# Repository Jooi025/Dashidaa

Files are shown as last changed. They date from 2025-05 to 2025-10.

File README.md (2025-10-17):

# Dashidaa
Meet Dashidaa, the robot car companion with a face and a personality! It smiles, blinks, and reacts as you drive. With a rechargeable battery and a smart power system, Dashidaa keeps itself charged and ready for your adventure.
## PCB
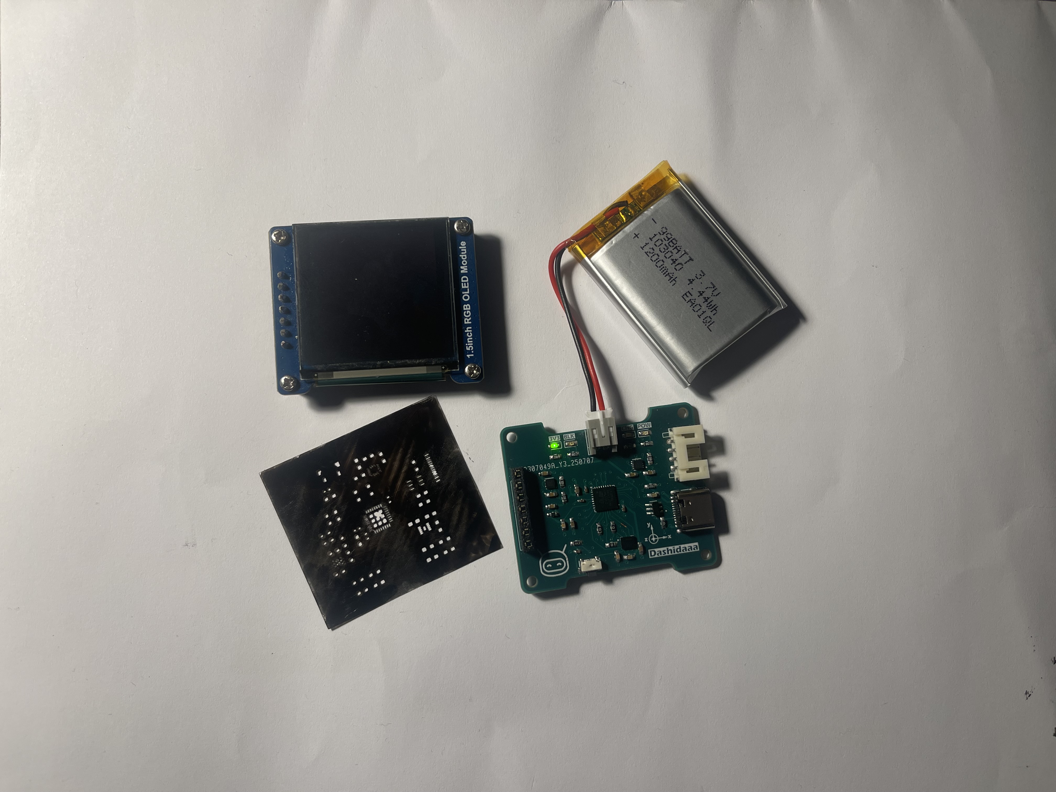
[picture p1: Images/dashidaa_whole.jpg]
PCB whole

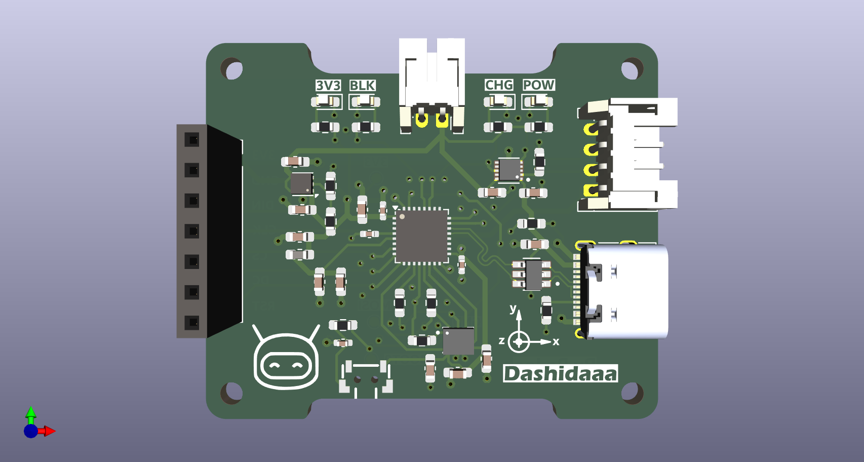
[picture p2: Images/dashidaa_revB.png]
PCB back

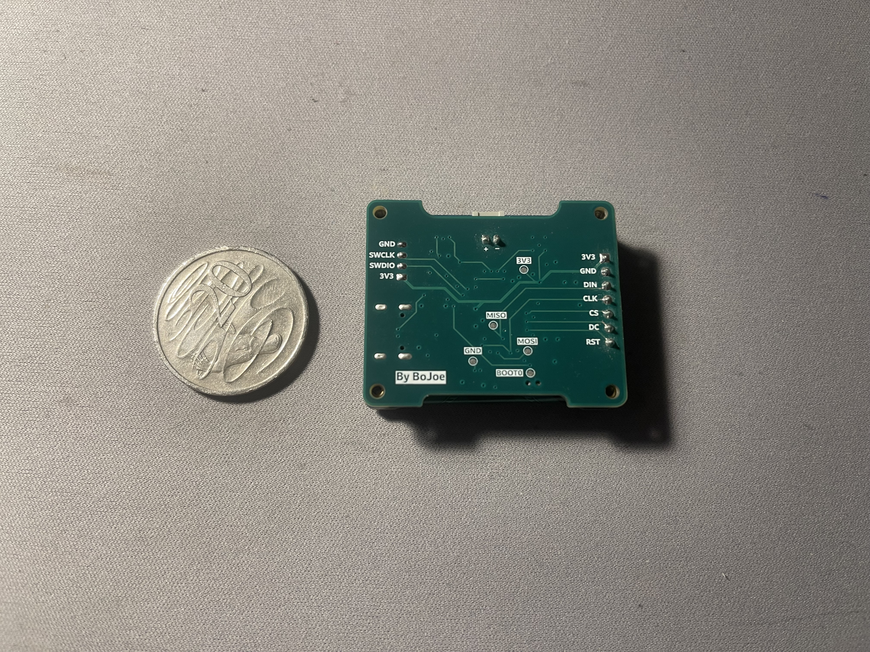
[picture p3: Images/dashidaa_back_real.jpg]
Actual PCB back

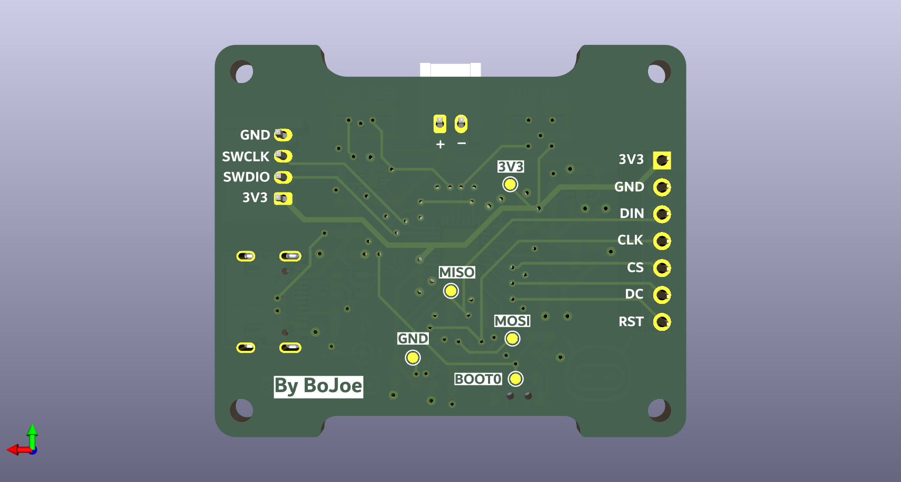
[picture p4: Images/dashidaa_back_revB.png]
PCB front


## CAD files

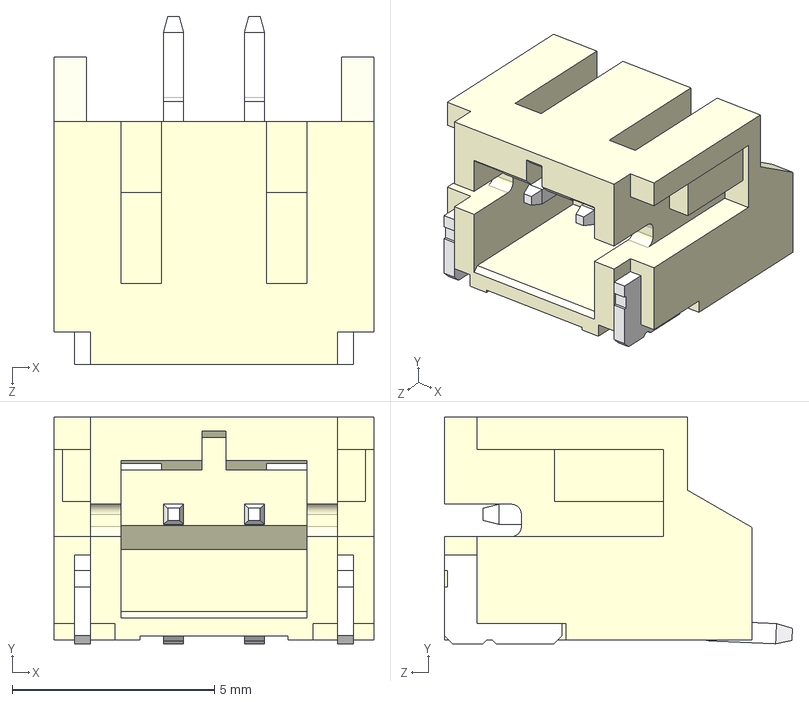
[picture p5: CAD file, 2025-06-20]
Hardware/cad_models/S2B-PH-SM4-TB.STEP
7.90 x 5.60 x 8.60 mm

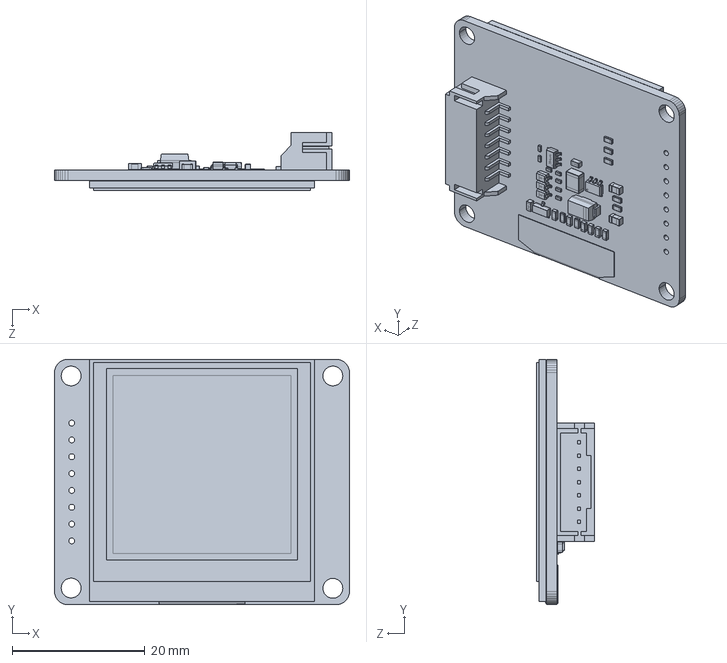
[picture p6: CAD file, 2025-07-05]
Hardware/cad_models/solidworks/1_5inch_oled_module.SLDPRT
44.5 x 37.0 x 8.70 mm

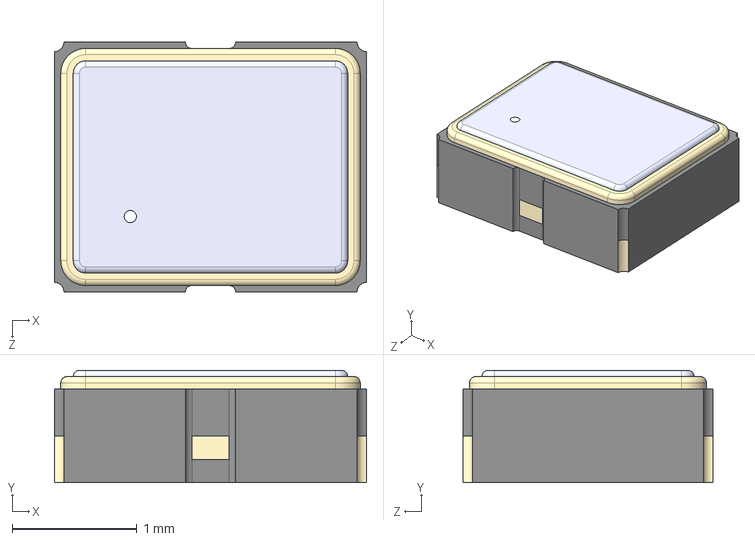
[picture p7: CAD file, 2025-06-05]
Hardware/external_components/ECS_2520MVQ_480_CN_TR/ECS-2520MVQ-480-CN-TR.step
2.50 x 0.9 x 2.00 mm

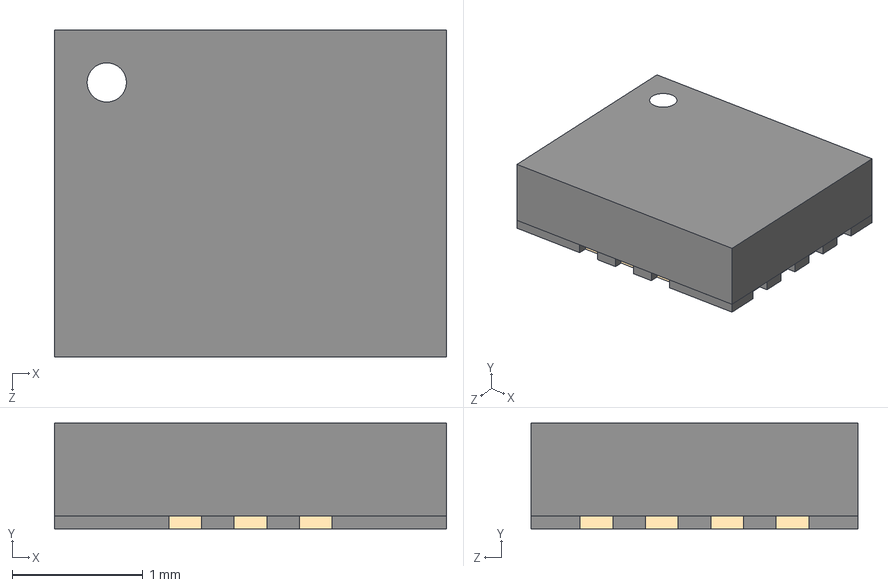
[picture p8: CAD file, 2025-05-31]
Hardware/external_components/ICM42670/ICM-42670-P.step
3.00 x 0.81 x 2.50 mm

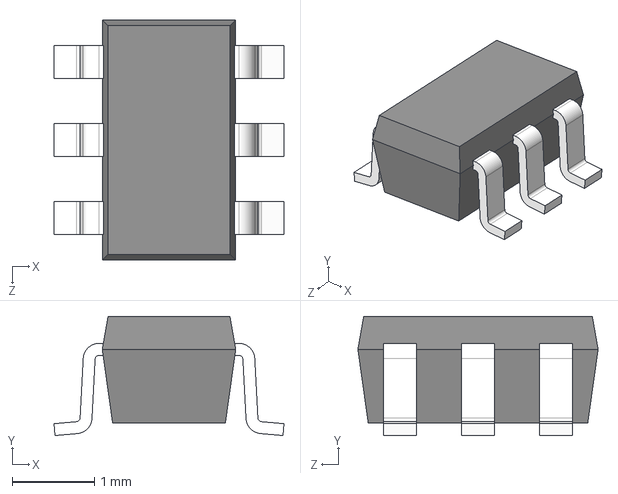
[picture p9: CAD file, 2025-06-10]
Hardware/external_components/USBLC6_2SC6/USBLC6-2SC6.step
2.80 x 1.45 x 2.92 mm

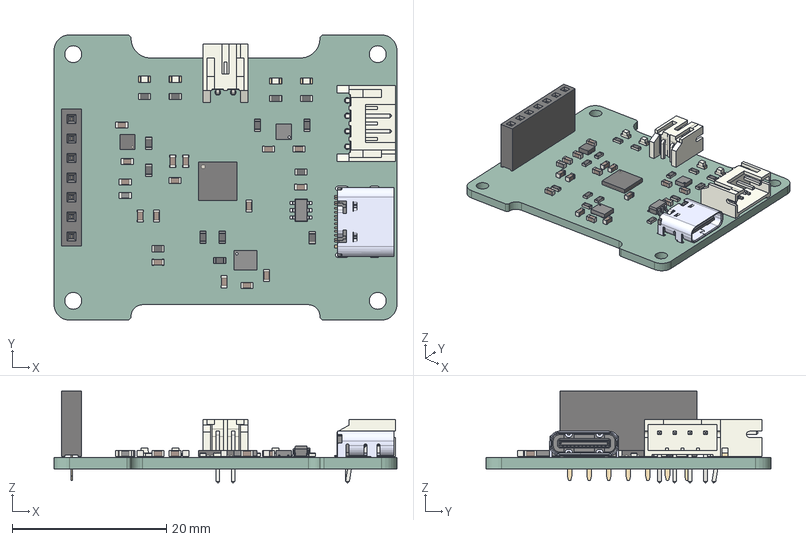
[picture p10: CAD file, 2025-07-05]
Hardware/RCC.step
44.5 x 37.0 x 11.9 mm
C_0603_1608Metric x 16
L_0603_1608Metric
WSON-6-1EP_2x2mm_P0.65mm_EP1x1.6mm
R_0603_1608Metric x 14
JST_PH_S4B-PH-K_1x04_P2.00mm_Horizontal
ICM-42670-P
LED_0603_1608Metric x 4
USB4105GFA_USB4105GFA
JST_PH_S2B-PH-K_1x02_P2.00mm_Horizontal
BQ24040DSQR
PinSocket_1x07_P2.54mm_Vertical
USBLC6-2SC6
QFN-32-1EP_5x5mm_P0.5mm_EP3.45x3.45mm
RCC_PCB

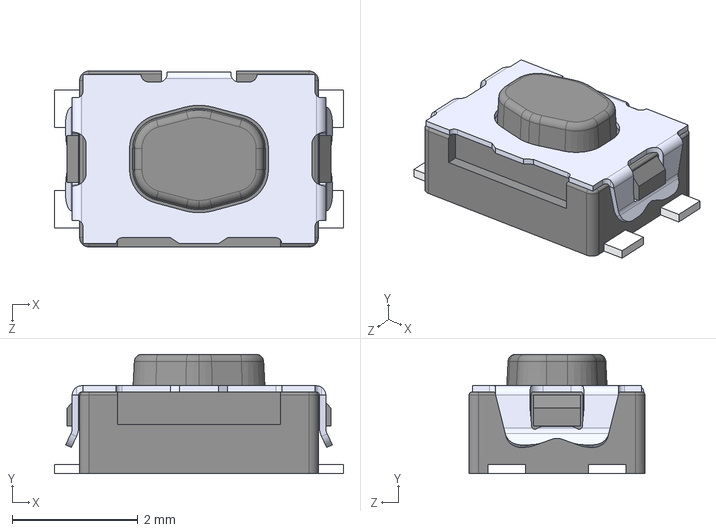
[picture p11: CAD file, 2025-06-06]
Hardware/cad_models/KMR211G LFS.STEP
4.60 x 1.90 x 2.80 mm

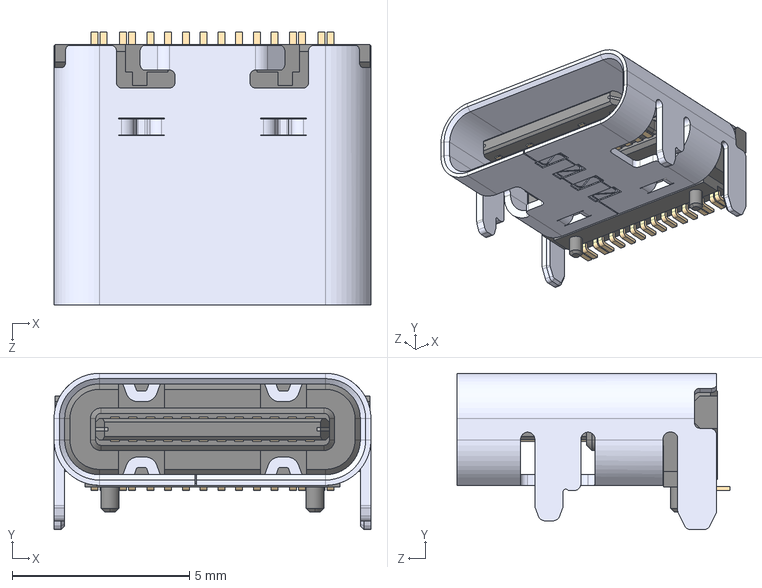
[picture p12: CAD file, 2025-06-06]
Hardware/cad_models/USB4105-GF-A--3DModel-STEP-510211.STEP
8.94 x 4.41 x 7.71 mm

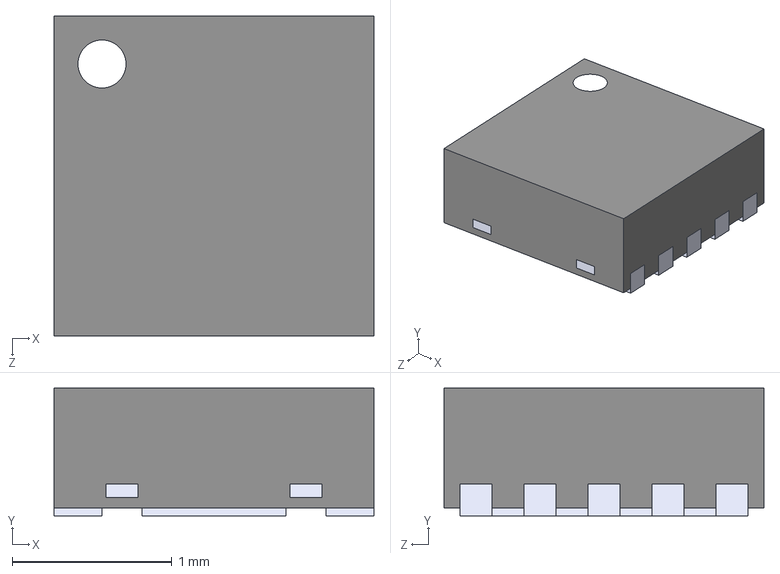
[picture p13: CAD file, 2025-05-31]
Hardware/external_components/BQ24040DSQR/BQ24040DSQR.step
2.00 x 0.8 x 2.00 mm

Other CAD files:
Hardware/cad_models/solidworks/RCC.SLDASM
Hardware/cad_models/solidworks/RCC.SLDPRT

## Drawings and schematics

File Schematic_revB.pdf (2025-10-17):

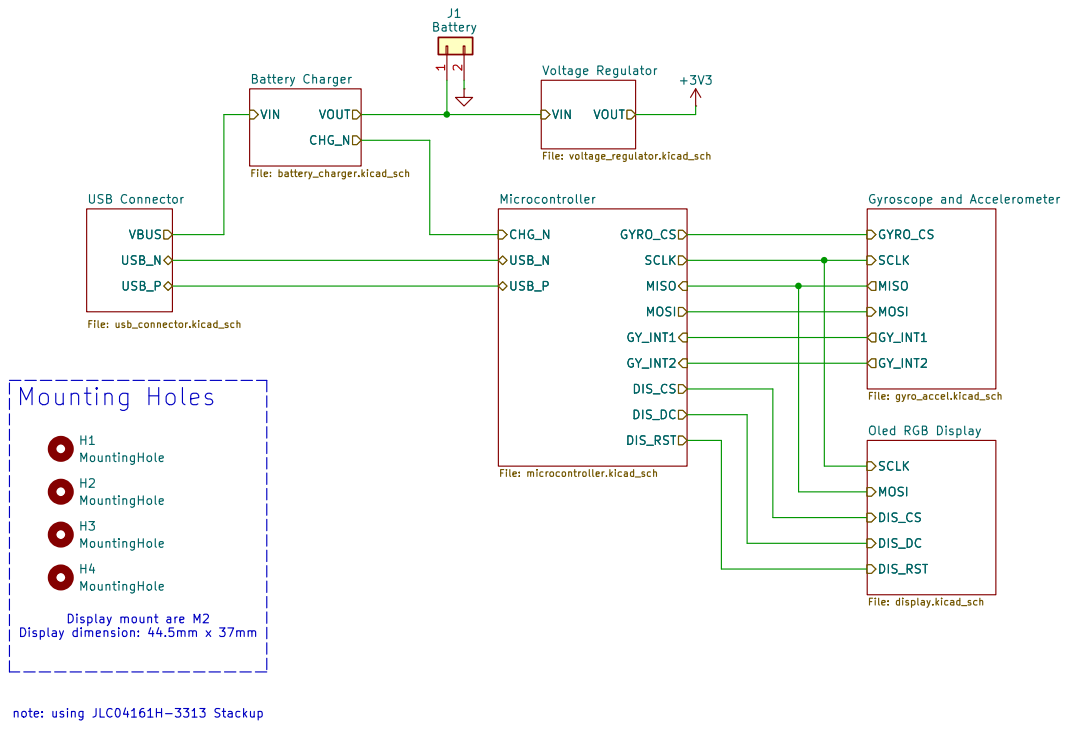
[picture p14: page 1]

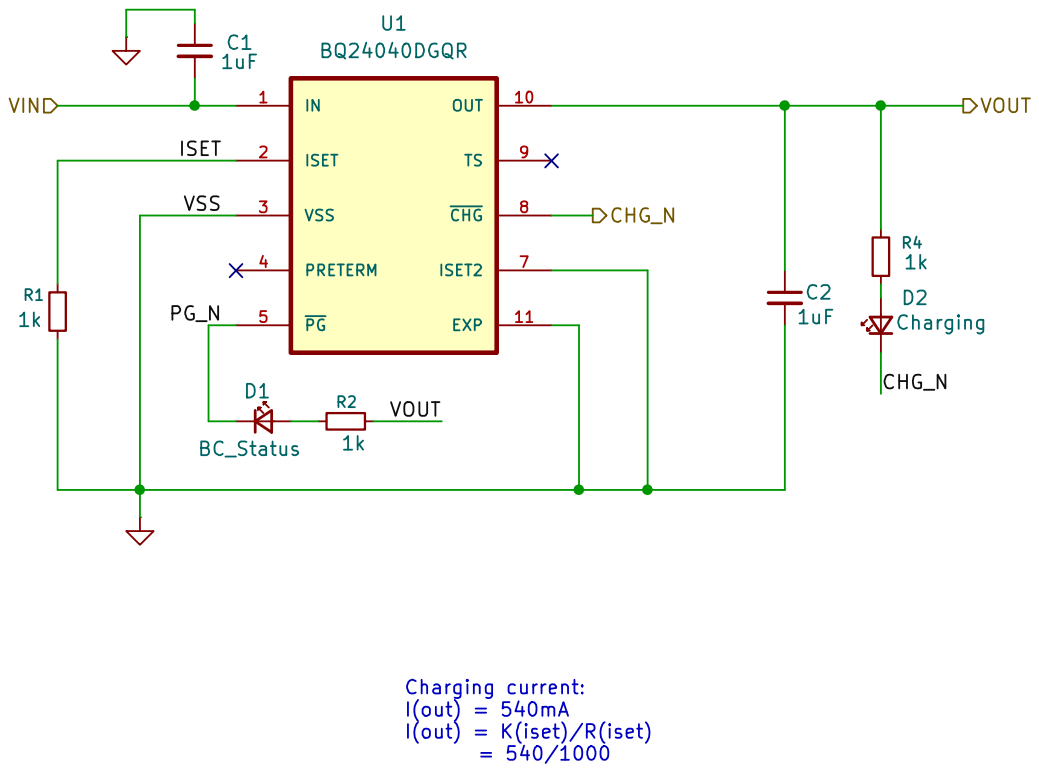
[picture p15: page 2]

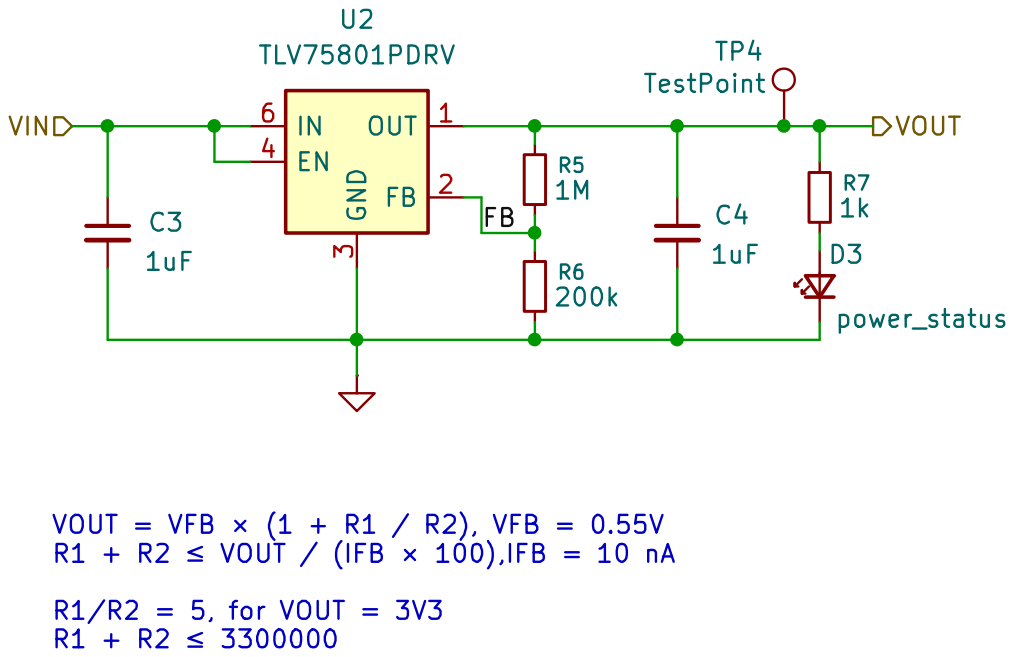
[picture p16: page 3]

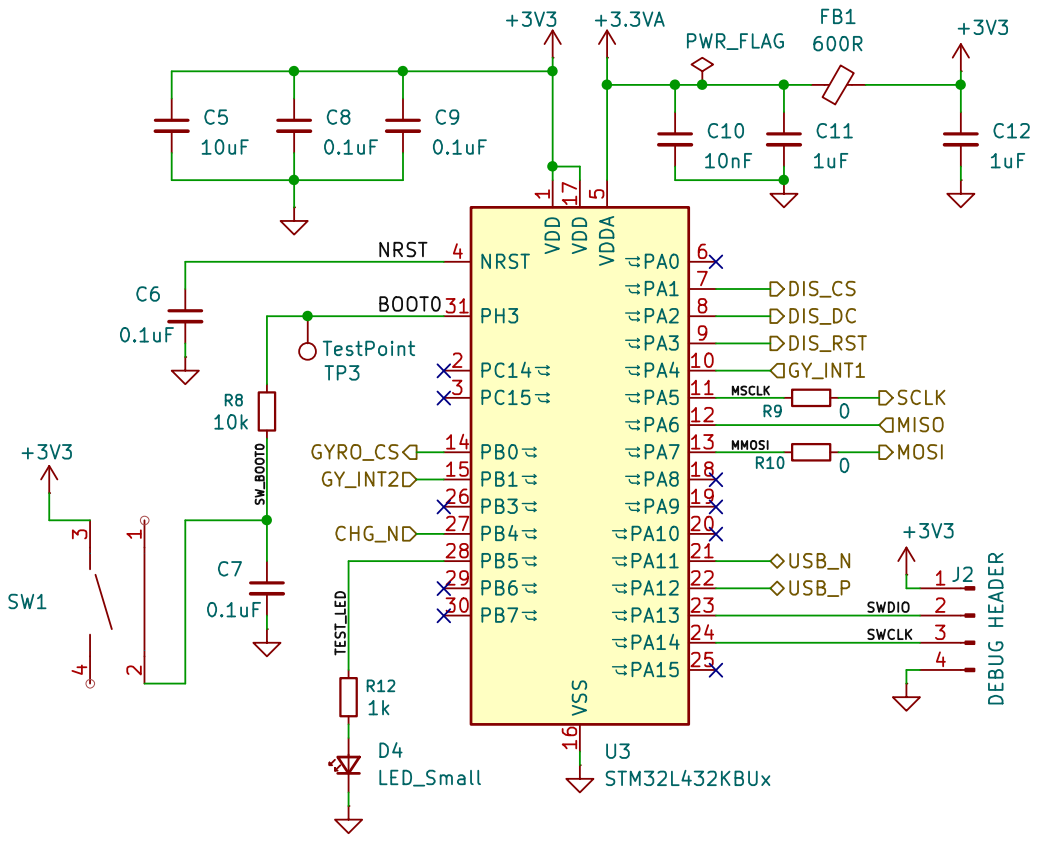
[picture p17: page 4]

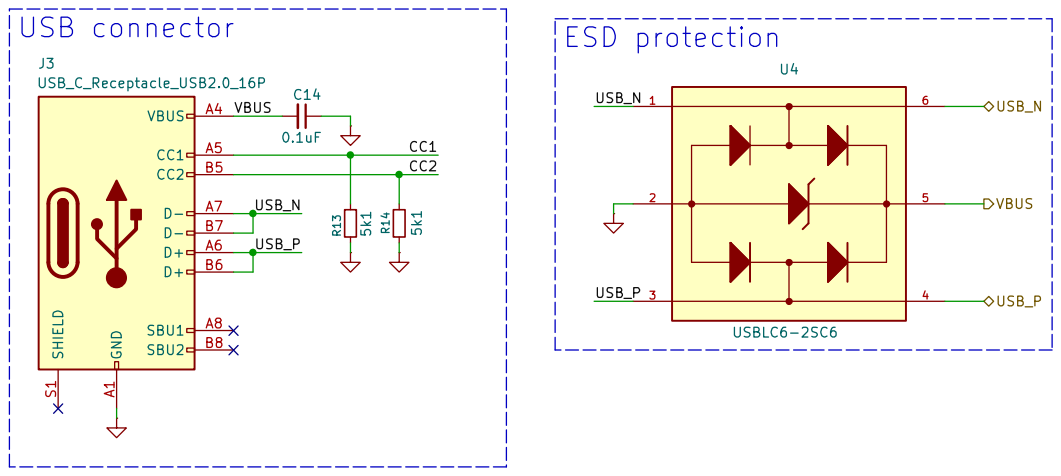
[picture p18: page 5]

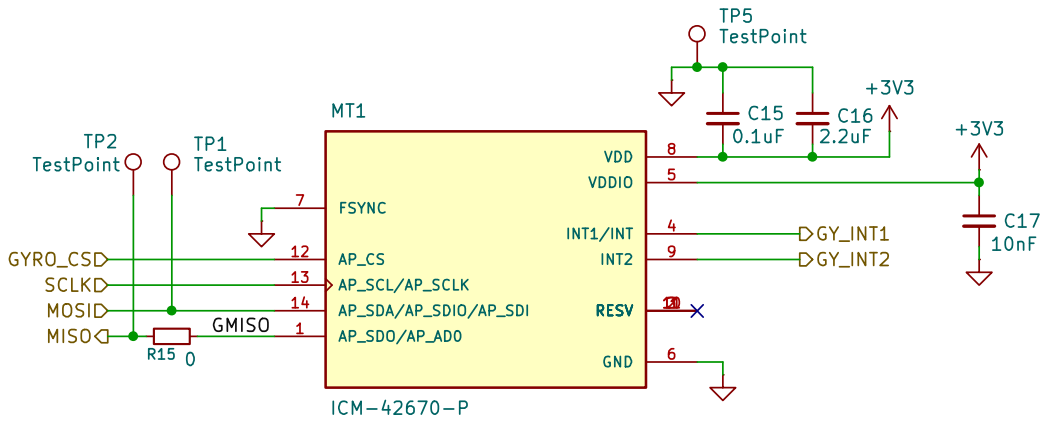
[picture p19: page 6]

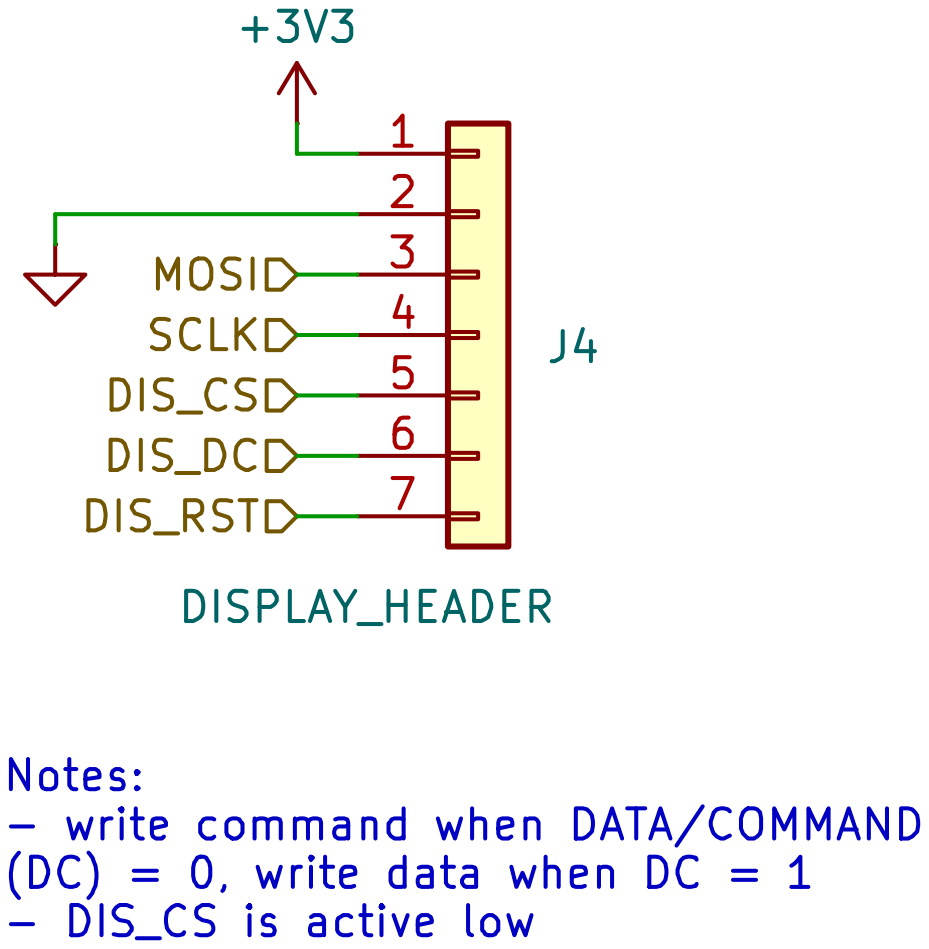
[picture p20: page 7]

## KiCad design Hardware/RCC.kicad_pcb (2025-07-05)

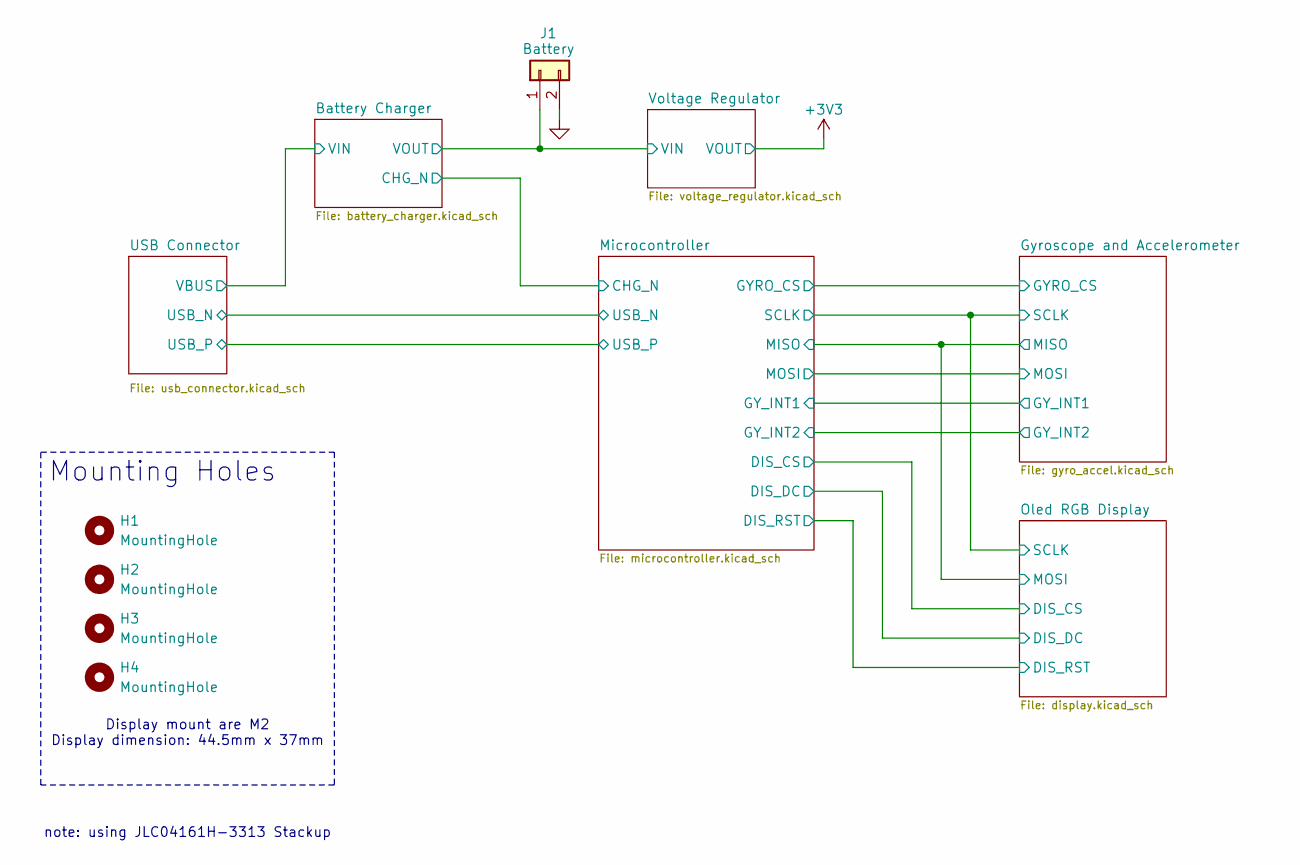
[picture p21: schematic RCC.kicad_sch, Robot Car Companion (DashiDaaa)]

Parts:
H1, H2, H3, H4: MountingHole; MountingHole_2.2mm_M2
J1: Battery; JST_PH_S2B-PH-K_1x02_P2.00mm_Horizontal

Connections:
/Battery Charger/VOUT: J1.1; also elsewhere on the board
GND: J1.2; also elsewhere on the board

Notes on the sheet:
Display mount are M2 Display dimension: 44.5mm x 37mm
note: using JLC04161H-3313 Stackup
Mounting Holes

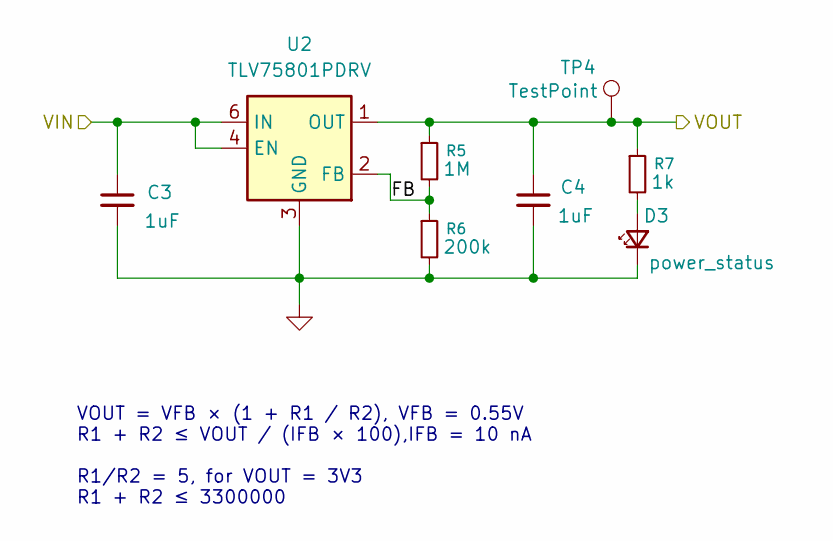
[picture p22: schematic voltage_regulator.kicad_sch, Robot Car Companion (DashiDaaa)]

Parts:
C3, C4: 1uF; C_0603_1608Metric_Pad1.08x0.95mm_HandSolder
D3: power_status; LED_0603_1608Metric_Pad1.05x0.95mm_HandSolder
R5: 1M; R_0603_1608Metric_Pad0.98x0.95mm_HandSolder
R6: 200k; R_0603_1608Metric_Pad0.98x0.95mm_HandSolder
R7: 1k; R_0603_1608Metric_Pad0.98x0.95mm_HandSolder
TP4: TestPoint; TestPoint_Pad_D1.0mm
U2: TLV75801PDRV; WSON-6-1EP_2x2mm_P0.65mm_EP1x1.6mm

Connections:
+3V3: C4.1, R5.1, R7.1, TP4.1, U2.1 (OUT); also elsewhere on the board
/Battery Charger/VOUT: C3.1, U2.4 (EN), U2.6 (IN); also elsewhere on the board
/Voltage Regulator/FB: R5.2, R6.1, U2.2 (FB)
GND: C3.2, C4.2, D3.1 (K), R6.2, U2.3 (GND), U2.7 (GND); also elsewhere on the board
unnamed: D3.2 (A), R7.2

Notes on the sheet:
VOUT = VFB × (1 + R1 / R2), VFB = 0.55V R1 + R2 ≤ VOUT / (IFB × 100),IFB = 10 nA R1/R2 = 5, for VOUT = 3V3 R1 + R2 ≤ 3300000

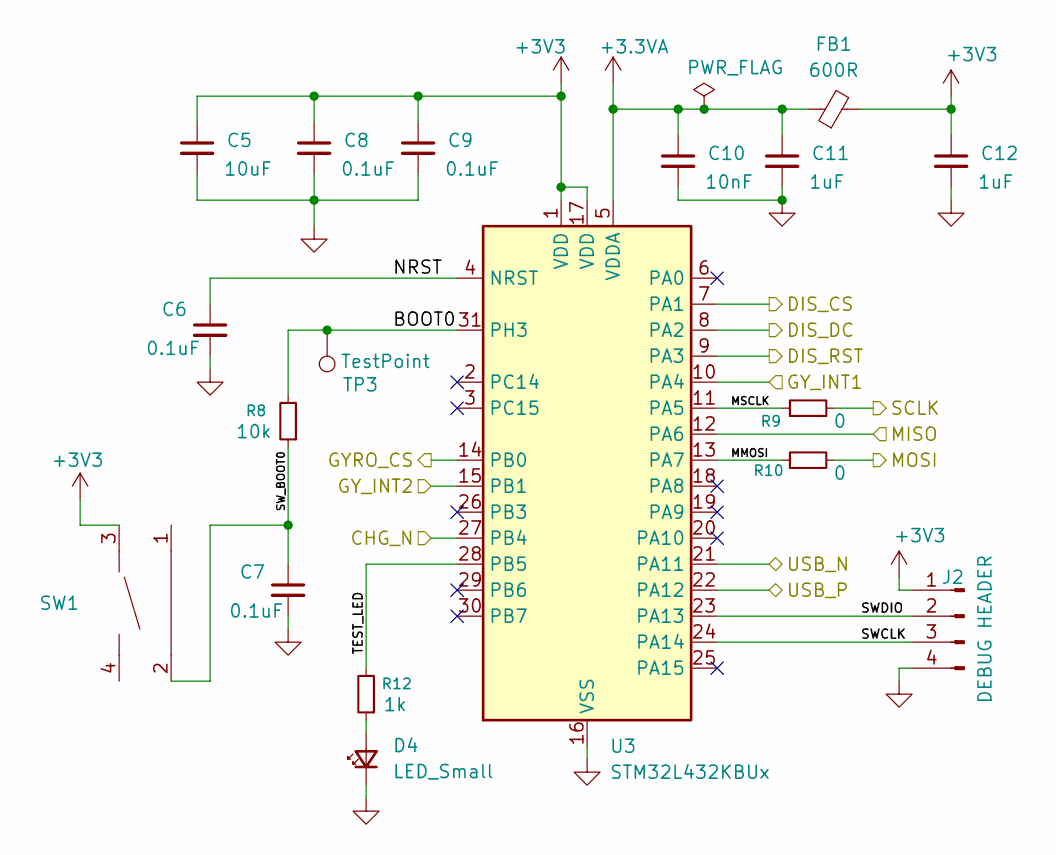
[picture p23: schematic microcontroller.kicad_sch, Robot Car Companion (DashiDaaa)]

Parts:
C5: 10uF; C_0603_1608Metric_Pad1.08x0.95mm_HandSolder
C6, C7, C8, C9: 0.1uF; C_0402_1005Metric_Pad0.74x0.62mm_HandSolder
C10: 10nF; C_0603_1608Metric_Pad1.08x0.95mm_HandSolder
C11, C12: 1uF; C_0603_1608Metric_Pad1.08x0.95mm_HandSolder
D4: LED_Small; LED_0603_1608Metric_Pad1.05x0.95mm_HandSolder
FB1: 600R; L_0603_1608Metric_Pad1.05x0.95mm_HandSolder
J2: DEBUG HEADER; JST_PH_S4B-PH-K_1x04_P2.00mm_Horizontal
R8: 10k; R_0603_1608Metric_Pad0.98x0.95mm_HandSolder
R9, R10: 0; R_0603_1608Metric_Pad0.98x0.95mm_HandSolder
R12: 1k; R_0603_1608Metric_Pad0.98x0.95mm_HandSolder
SW1: SW-SMD_TS24CA; Manufacturer Part TS24CA; LCSC Part Name 4.55*1.8*3.5mm 卧贴 轻触开关
TP3: TestPoint; TestPoint_Pad_D1.0mm
U3: STM32L432KBUx; QFN-32-1EP_5x5mm_P0.5mm_EP3.45x3.45mm

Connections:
+3.3VA: C10.1, C11.1, FB1.1, U3.5 (VDDA)
+3V3: C5.1, C8.1, C9.1, C12.1, FB1.2, J2.1, SW1.3, U3.1 (VDD), U3.17 (VDD); also elsewhere on the board
/Battery Charger/CHG_N: U3.27 (PB4); also elsewhere on the board
/Gyroscope and Accelerometer/GYRO_CS: U3.14 (PB0); also elsewhere on the board
/Gyroscope and Accelerometer/GY_INT1: U3.10 (PA4); also elsewhere on the board
/Gyroscope and Accelerometer/GY_INT2: U3.15 (PB1); also elsewhere on the board
/Gyroscope and Accelerometer/MISO: U3.12 (PA6); also elsewhere on the board
/Gyroscope and Accelerometer/MOSI: R10.2; also elsewhere on the board
/Gyroscope and Accelerometer/SCLK: R9.2; also elsewhere on the board
/Microcontroller/BOOT0: R8.2, TP3.1, U3.31 (PH3)
/Microcontroller/DIS_CS: U3.7 (PA1); also elsewhere on the board
/Microcontroller/DIS_DC: U3.8 (PA2); also elsewhere on the board
/Microcontroller/DIS_RST: U3.9 (PA3); also elsewhere on the board
/Microcontroller/MMOSI: R10.1, U3.13 (PA7)
/Microcontroller/MSCLK: R9.1, U3.11 (PA5)
/Microcontroller/NRST: C6.1, U3.4 (NRST)
/Microcontroller/SWCLK: J2.3, U3.24 (PA14)
/Microcontroller/SWDIO: J2.2, U3.23 (PA13)
/Microcontroller/SW_BOOT0: C7.1, R8.1, SW1.2
/Microcontroller/TEST_LED: R12.2, U3.28 (PB5)
/USB Connector/USB_N: U3.21 (PA11); also elsewhere on the board
/USB Connector/USB_P: U3.22 (PA12); also elsewhere on the board
GND: C5.2, C6.2, C7.2, C8.2, C9.2, C10.2, C11.2, C12.2, D4.1 (K), J2.4, U3.16 (VSS), U3.32 (VSS), U3.33 (VSS); also elsewhere on the board
unnamed: D4.2 (A), R12.1

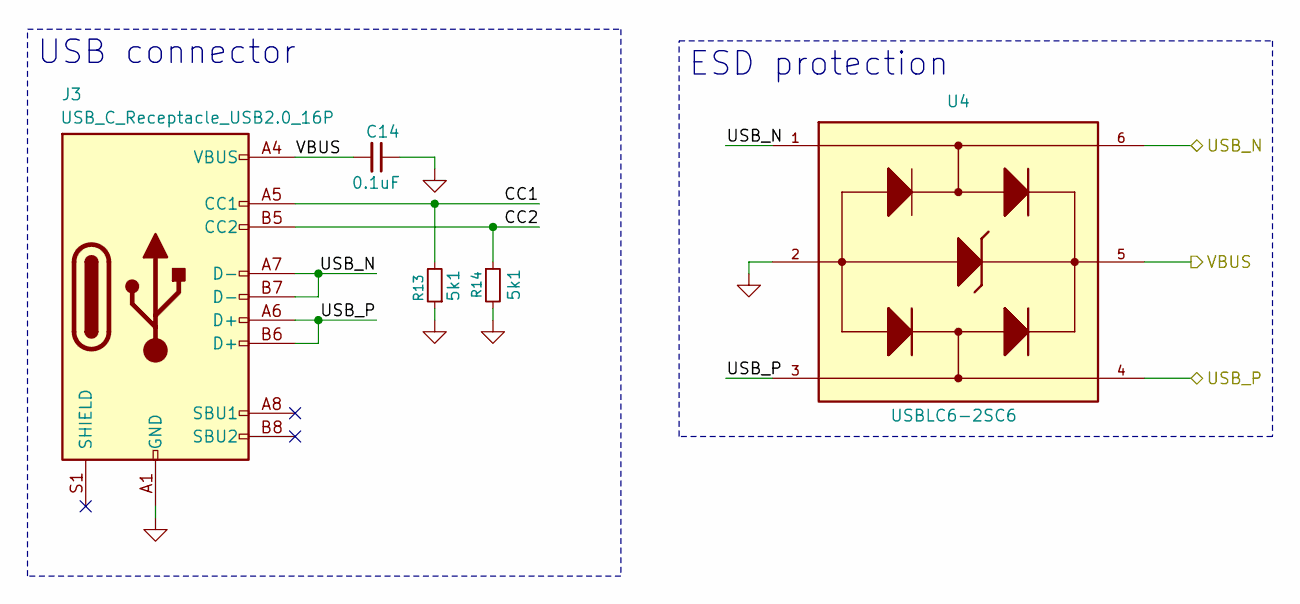
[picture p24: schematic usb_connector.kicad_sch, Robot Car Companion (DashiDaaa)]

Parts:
C14: 0.1uF; C_0603_1608Metric_Pad1.08x0.95mm_HandSolder
J3: USB_C_Receptacle_USB2.0_16P; USB_C_Receptacle_G-Switch_GT-USB-7010ASV
R13, R14: 5k1; R_0603_1608Metric_Pad0.98x0.95mm_HandSolder
U4: USBLC6-2SC6; SOT95P280X145-6N

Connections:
/USB Connector/CC1: J3.A5 (CC1), R13.2
/USB Connector/CC2: J3.B5 (CC2), R14.1
/USB Connector/USB_N: J3.A7 (D-), J3.B7 (D-), U4.1, U4.6; also elsewhere on the board
/USB Connector/USB_P: J3.A6 (D+), J3.B6 (D+), U4.3, U4.4; also elsewhere on the board
/USB Connector/VBUS: C14.2, J3.A4 (VBUS), J3.A9 (VBUS), J3.B4 (VBUS), J3.B9 (VBUS), U4.5; also elsewhere on the board
GND: C14.1, J3.A1 (GND), J3.A12 (GND), J3.B1 (GND), J3.B12 (GND), R13.1, R14.2, U4.2; also elsewhere on the board

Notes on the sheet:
ESD protection
USB connector

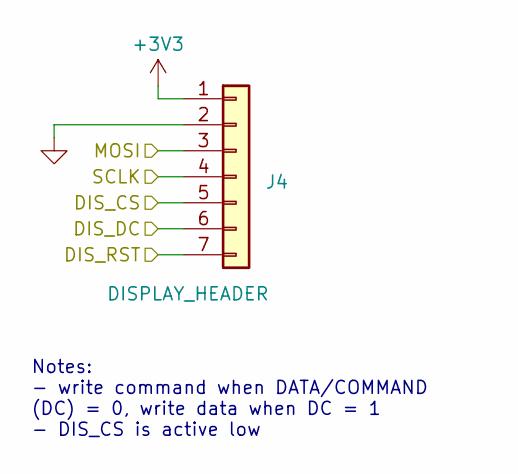
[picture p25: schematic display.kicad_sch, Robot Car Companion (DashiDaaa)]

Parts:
J4: DISPLAY_HEADER; PinSocket_1x07_P2.54mm_Vertical

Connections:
+3V3: J4.1; also elsewhere on the board
/Gyroscope and Accelerometer/MISO: J4.3; also elsewhere on the board
/Gyroscope and Accelerometer/SCLK: J4.4; also elsewhere on the board
/Microcontroller/DIS_CS: J4.5; also elsewhere on the board
/Microcontroller/DIS_DC: J4.6; also elsewhere on the board
/Microcontroller/DIS_RST: J4.7; also elsewhere on the board
GND: J4.2; also elsewhere on the board

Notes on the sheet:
Notes: - write command when DATA/COMMAND (DC) = 0, write data when DC = 1 - DIS_CS is active low

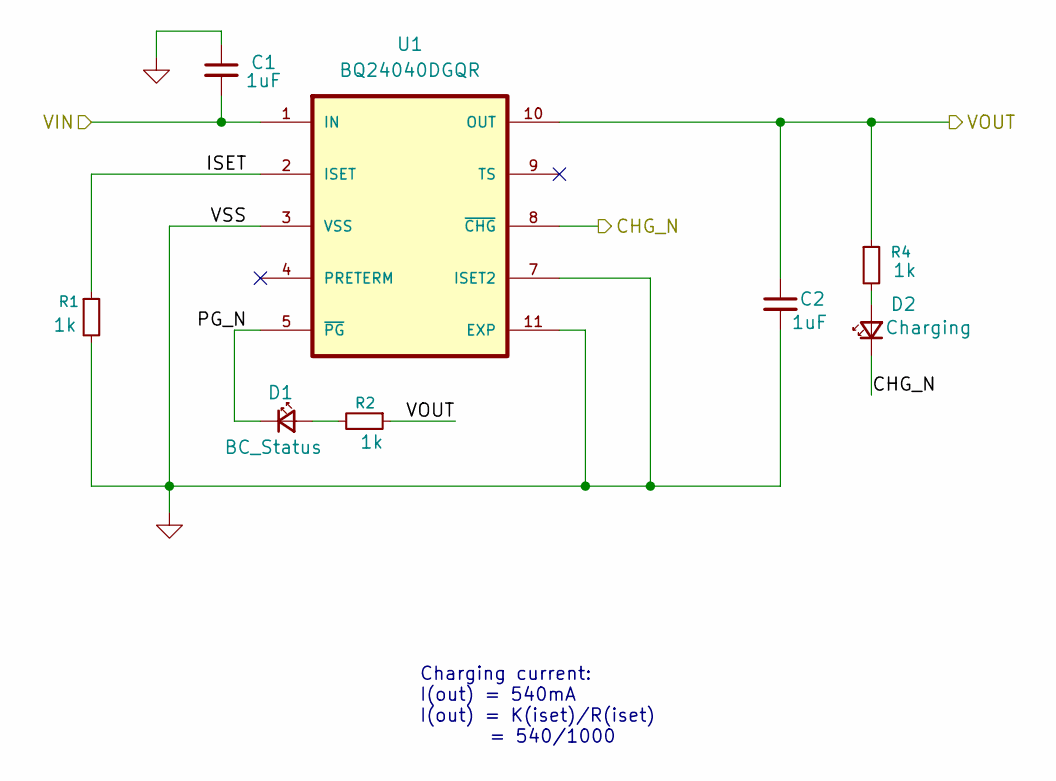
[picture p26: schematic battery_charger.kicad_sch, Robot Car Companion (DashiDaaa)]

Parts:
C1, C2: 1uF; C_0603_1608Metric_Pad1.08x0.95mm_HandSolder
D1: BC_Status; LED_0603_1608Metric_Pad1.05x0.95mm_HandSolder
D2: Charging; LED_0603_1608Metric_Pad1.05x0.95mm_HandSolder
R1, R2, R4: 1k; R_0603_1608Metric_Pad0.98x0.95mm_HandSolder
U1: BQ24040DGQR; SON40P200X200X80-11N

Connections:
/Battery Charger/CHG_N: D2.1 (K), U1.8 (~CHG); also elsewhere on the board
/Battery Charger/ISET: R1.1, U1.2 (ISET)
/Battery Charger/PG_N: D1.1 (K), U1.5 (~PG)
/Battery Charger/VOUT: C2.1, R2.1, R4.1, U1.10 (OUT); also elsewhere on the board
/USB Connector/VBUS: C1.2, U1.1 (IN); also elsewhere on the board
GND: C1.1, C2.2, R1.2, U1.3 (VSS), U1.7 (ISET2), U1.11 (EXP); also elsewhere on the board
unnamed: D1.2 (A), R2.2
unnamed: D2.2 (A), R4.2

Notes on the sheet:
Charging current: I(out) = 540mA I(out) = K(iset)/R(iset) = 540/1000

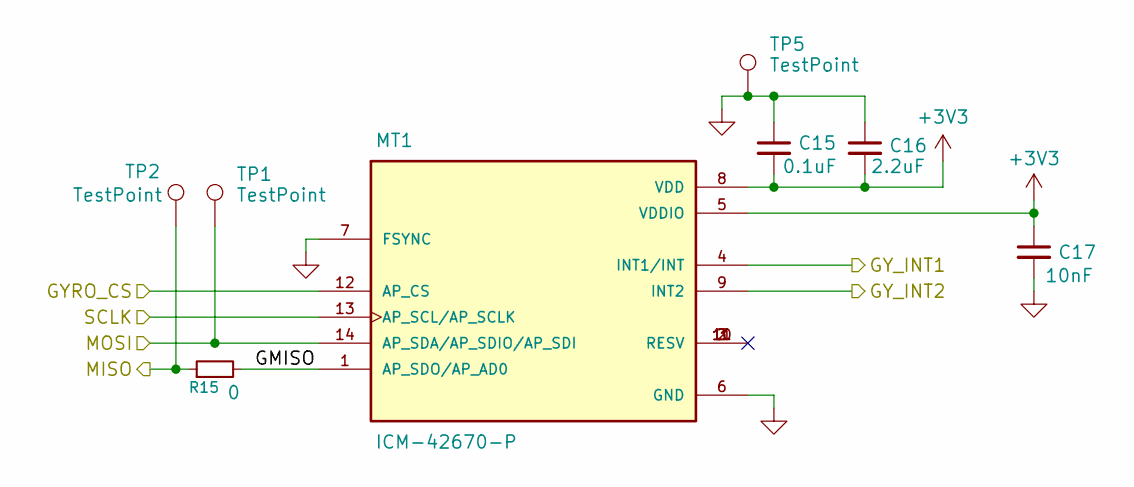
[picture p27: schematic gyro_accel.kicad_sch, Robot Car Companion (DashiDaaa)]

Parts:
C15: 0.1uF; C_0603_1608Metric_Pad1.08x0.95mm_HandSolder
C16: 2.2uF; C_0603_1608Metric_Pad1.08x0.95mm_HandSolder
C17: 10nF; C_0603_1608Metric_Pad1.08x0.95mm_HandSolder
MT1: ICM-42670-P; XDCR_ICM-42670-P; PARTREV 1.1
R15: 0; R_0603_1608Metric_Pad0.98x0.95mm_HandSolder
TP1, TP2, TP5: TestPoint; TestPoint_Pad_D1.0mm

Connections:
+3V3: C15.2, C16.2, C17.1, MT1.5 (VDDIO), MT1.8 (VDD); also elsewhere on the board
/Gyroscope and Accelerometer/GMISO: MT1.1 (AP_SDO/AP_AD0), R15.2
/Gyroscope and Accelerometer/GYRO_CS: MT1.12 (AP_CS); also elsewhere on the board
/Gyroscope and Accelerometer/GY_INT1: MT1.4 (INT1/INT); also elsewhere on the board
/Gyroscope and Accelerometer/GY_INT2: MT1.9 (INT2); also elsewhere on the board
/Gyroscope and Accelerometer/MISO: R15.1, TP2.1; also elsewhere on the board
/Gyroscope and Accelerometer/MOSI: MT1.14 (AP_SDA/AP_SDIO/AP_SDI), TP1.1; also elsewhere on the board
/Gyroscope and Accelerometer/SCLK: MT1.13 (AP_SCL/AP_SCLK); also elsewhere on the board
GND: C15.1, C16.1, C17.2, MT1.6 (GND), MT1.7 (FSYNC), TP5.1; also elsewhere on the board

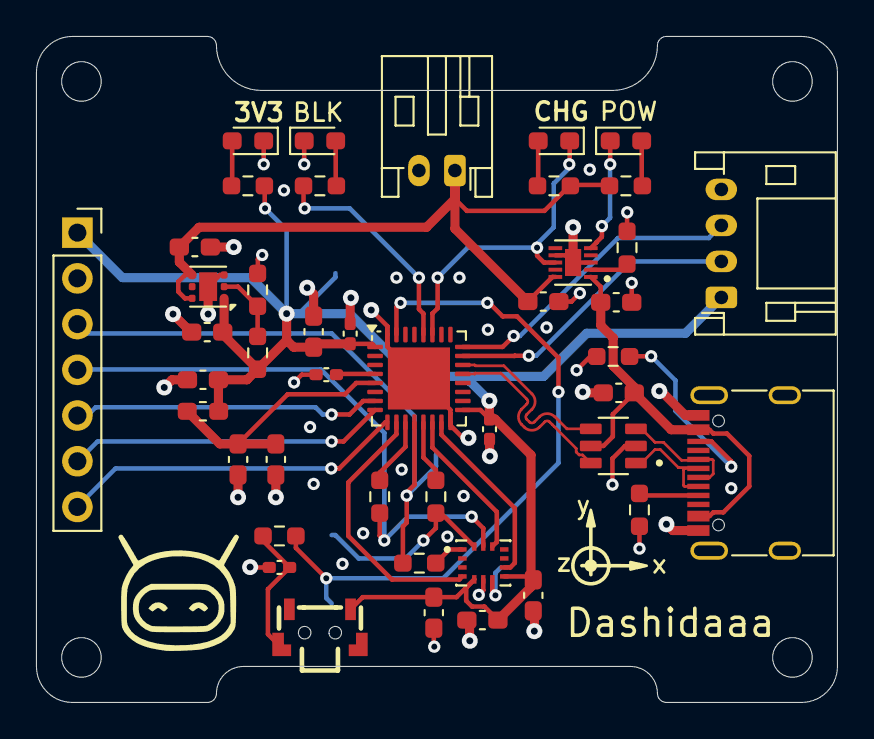
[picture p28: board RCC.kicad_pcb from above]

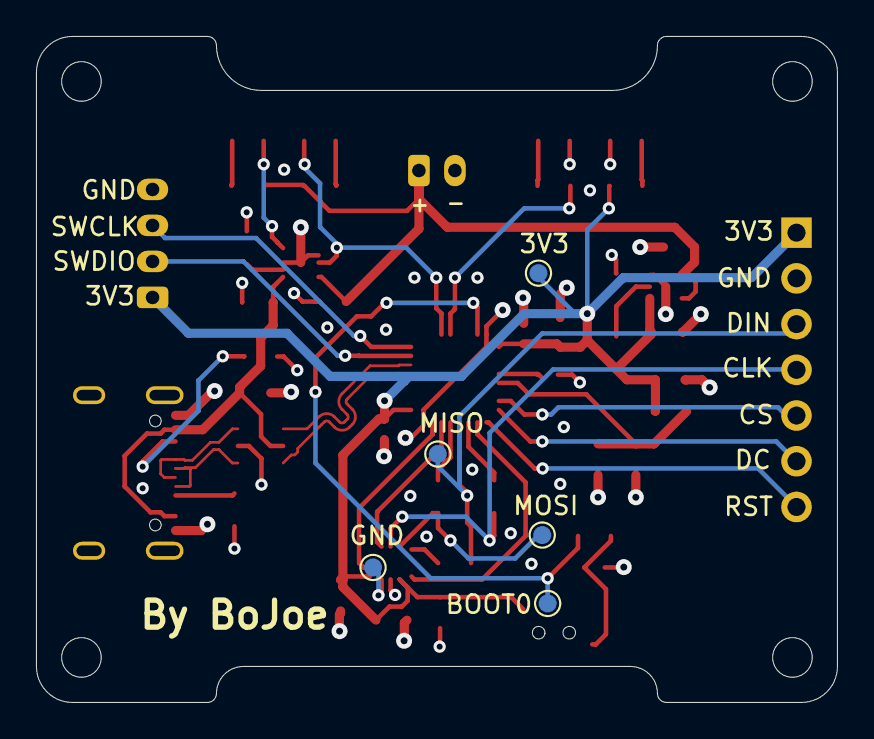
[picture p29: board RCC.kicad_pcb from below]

Board: 4 copper layers, 44.5 x 37.0 mm, 53 parts (5 on the bottom side), 35 nets.

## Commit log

2025-05-31 Upload KiCad project
    [BQ24040DSQR.step, ICM-42670-P.step, RCC.kicad_pcb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]
2025-05-31 Add microcontroller and display to schematic
    [RCC.kicad_sch]
2025-06-01 Add resistor value for regulator and pull up resistor and debug connector for microcontroller
    [RCC.kicad_sch]
2025-06-04 Initial PCB layout
    [RCC.kicad_pcb, RCC.kicad_sch]
2025-06-05 Change PCB stackup to 4 layer
    [RCC.kicad_pcb, RCC.kicad_sch]
2025-06-05 Add crystal in schematic and pcb
    [ECS-2520MVQ-480-CN-TR.step, RCC.kicad_pcb, RCC.kicad_sch]
2025-06-06 Finalise PCB and add 3d models
    [ESD7104MUTAG.STEP, KMR211G LFS.STEP, RCC.kicad_pcb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]
2025-06-06 Change connectors to jst-ph
    [RCC.kicad_pcb, RCC.kicad_sch]
2025-06-06 Add PCB image
2025-06-07 Clean up pcb traces and vias
    [RCC.kicad_pcb]
2025-06-10 Add termination resistor to spi and change esd protection
    [RCC.kicad_sch, USBLC6-2SC6.step]
2025-06-20 Restructure folder and start revB
    [BQ24040DSQR.step, ECS-2520MVQ-480-CN-TR.step, ESD7104MUTAG.STEP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]
2025-07-02 Finish routing revB
    [RCC.kicad_pcb, RCC.kicad_sch]
2025-07-02 Add multiple page of schematic
    [battery_charger.kicad_sch, display.kicad_sch, gyro_accel.kicad_sch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]
2025-07-02 Add silkscreen to pcb
    [RCC.kicad_pcb, microcontroller.kicad_sch]
2025-07-05 Finnish RevB
    [1_5inch_oled_module.SLDPRT, RCC.SLDASM, RCC.SLDPRT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]
2025-07-05 Add revB pcb image
2025-10-17 Restructure folders
    [1_5inch_oled_module.SLDPRT, BQ24040DSQR.step, ECS-2520MVQ-480-CN-TR.step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]
